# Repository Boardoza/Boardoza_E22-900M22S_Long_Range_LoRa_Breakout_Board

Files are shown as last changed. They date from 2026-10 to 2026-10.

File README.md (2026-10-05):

# Boardoza E22-900M22S LoRa® Breakout Board

The **Boardoza E22-900M22S Breakout Board** is a compact long-range wireless communication board based on the **Ebyte E22-900M22S** LoRa® module. Powered by the **Semtech SX1262** RF transceiver, it supports both **LoRa®** and **FSK(Frequency Shift Keying)** modulation, enabling reliable low-power wireless communication over the **850–930 MHz ISM frequency range**, including the widely used **868 MHz** and **915 MHz** bands. The onboard **32 MHz TCXO (Temperature Compensated Crystal Oscillator)** provides excellent frequency stability, making it suitable for narrowband communication and outdoor deployments.

The breakout board exposes the module's **SPI interface**, RF control signals, and status pins through standard headers, allowing easy integration with development platforms such as **STM32**, **ESP32**, **Arduino, and other 3.3V-compatible microcontrollers**. With its SMA antenna connector, industrial operating temperature range, and long communication distance, this board is ideal for **IoT gateways, smart agriculture, telemetry, environmental monitoring, industrial automation, and wireless sensor networks**.

---

## Key Features

- **Long-Range LoRa® Communication:** Based on the Semtech SX1262 transceiver for reliable long-distance wireless links.
- **868 / 915 MHz ISM Band Support:** Compatible with license-free ISM bands used worldwide.
- **High RF Output Power:** Up to **22 dBm (160 mW)** transmit power with software-adjustable output levels.
- **LoRa® and FSK Modulation Support:** Provides air data rates from 0.018 to 62.5 kbps in LoRa® mode and up to 300 kbps in FSK mode.
- **Stable RF Performance:** Integrated **32 MHz TCXO** improves frequency stability over temperature.
- **Easy MCU Integration:** Standard **4-wire SPI interface** with dedicated control and status signals.
- **SMA Antenna Connector:** Ready for external antennas with improved RF performance.
- **Ideal for IoT Applications:** Suitable for wireless sensor networks, smart agriculture, telemetry, industrial monitoring, and remote data acquisition.

---

## Technical Specifications

**Model:** E22-900M22S   
**Manufacturer:** Boardoza    
**Manufacturer IC:** Chengdu Ebyte Electronic Technology Co., Ltd.   
**RF Transceiver:** Semtech SX1262  
**Input Voltage:** 3.3V – 5.5V     
**Interface:** SPI  
**Frequency Range:** 850 – 930 MHz     
**Maximum RF Output Power:** 22 dBm (160 mW)  
**Maximum Air Data Rate (LoRa®):** 0.018 to 62.5 kbps  
**Maximum Air Data Rate (FSK):** 300 kbps  
**FIFO Buffer:** 256 Bytes  
**Oscillator:** High-Precision 32 MHz TCXO  
**Antenna Connector:** SMA Female  
**Operating Temperature:** -40°C to +85°C  
**Board Dimensions:** 40 mm × 20 mm

---

## Board Pinout

### ( J1 ) SPI Interface

| Pin Number | Pin Name | Description |
|:---:|:---:|---|
| 1 | VCC | Power Input |
| 2 | MISO | SPI Data Output |
| 3 | MOSI | SPI Data Input |
| 4 | SCK | SPI Clock |
| 5 | nCS | SPI Chip Select (Active Low) |
| 6 | GND | Ground |

### ( J2 ) Control Signals

| Pin Number | Pin Name | Description |
|:---:|:---:|---|
| 1 | NRST | Reset Input (Active Low) |
| 2 | BUSY | Module Busy Status Output |
| 3 | DIO1 | Configurable Digital I/O |

### ( J3 ) RF Switch & Control

| Pin Number | Pin Name | Description |
|:---:|:---:|---|
| 1 | RXEN | RF Receive Enable (Active High) |
| 2 | TXEN | RF Transmit Enable (Active High) |
| 3 | DIO2 | Configurable Digital I/O / RF Switch Control |

### ( J4 ) RF Connector

| Connector | Description |
|:---:|---|
| SMA Female | External 50Ω Antenna Connection |

---

## Board Dimensions

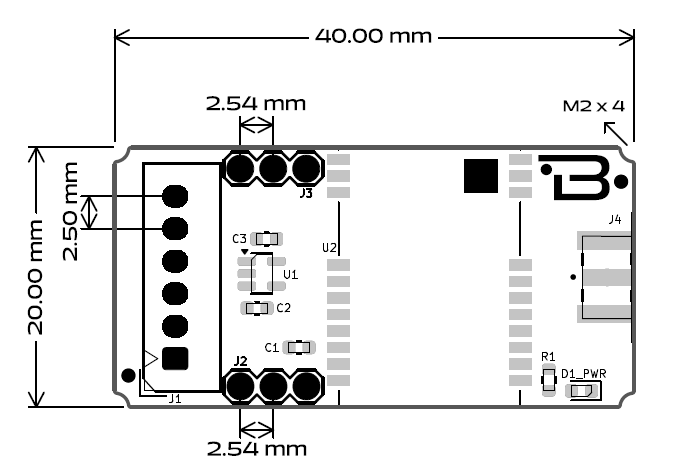
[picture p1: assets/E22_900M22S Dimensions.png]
Board Dimensions


---

## Step Files

[Boardoza E22-900M22S.step](./assets/E22_900M22S%20Step.step)

---

## Datasheet

[E22-900M22S Datasheet.pdf](./assets/E22-900M22S%20Datasheet.pdf)

---

## Version History

- V1.0.0 - Initial Release

---

## Support

- If you have any questions or need support, please contact **support@boardoza.com**

---

## **License**

This repository contains both hardware and software components:

### **Hardware Design**

[][cc-by-sa]

All hardware design files are licensed under [Creative Commons Attribution-ShareAlike 4.0 International License][cc-by-sa].

[cc-by-sa]: http://creativecommons.org/licenses/by-sa/4.0/
[cc-by-sa-shield]: https://img.shields.io/badge/License-CC%20BY--SA%204.0-lightgrey.svg

### **Software/Firmware**

[][bsd]

All software and firmware are licensed under [BSD 3-Clause License][bsd].

[bsd]: https://opensource.org/licenses/BSD-3-Clause
[bsd-shield]: https://img.shields.io/badge/License-BSD%203--Clause-blue.svg

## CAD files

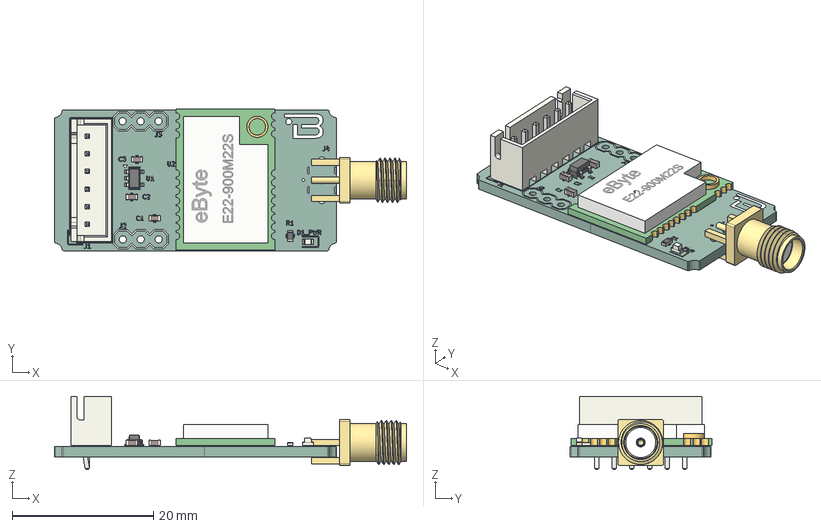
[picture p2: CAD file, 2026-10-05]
assets/E22_900M22S Step.step
49.9 x 20.1 x 10.4 mm
E22-900M22S v2
R_0603_1608Metric
C_0603_1608Metric x 3
Dielectric
Pin
SOT-23-5
JST_XH_B6B-XH-A_1x06_P2.50mm_Vertical
LED_0603_1608Metric
B-E22_900M22S-Brk-R1.0_silkscreen
B-E22_900M22S-Brk-R1.0_PCB

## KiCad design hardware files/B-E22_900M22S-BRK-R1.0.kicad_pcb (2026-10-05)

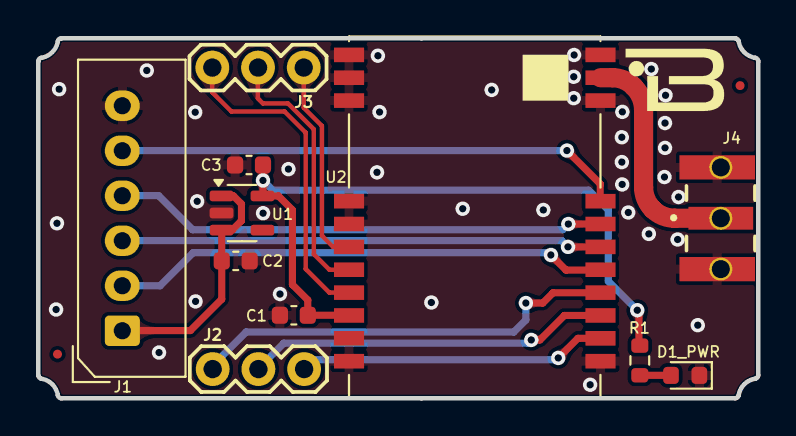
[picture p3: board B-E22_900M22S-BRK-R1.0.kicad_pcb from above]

Board: 2 copper layers, 40.0 x 20.0 mm, 11 parts (0 on the bottom side), 15 nets.

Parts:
C1: 100nF; C_0603_1608Metric
C2, C3: 1uF; C_0603_1608Metric
D1_PWR: LED POWER; LED_0603_1608Metric
J1: 2317-06S; 2317-06S_1x06_P2.50mm_Vertical
J2, J3: CONN_03; 1X03
J4: SMA; SMA-J-P-H-ST-EM1
R1: 330R; R_0603_1608Metric
U1: TLV73333PDBVR; SOT-23-5
U2: E22-400M22S; E22-900M22S

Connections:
+3V3: C1.1, C3.1, R1.1, U1.5 (OUT), U2.P$9 (VCC)
ANT: J4.1, U2.ANT
BUSY: J2.2, U2.P$14 (BUSY)
CS: J1.5, U2.P$19 (NSS)
DIO1: J2.3, U2.P$13 (DIO1)
DIO2: J3.3, U2.P$8 (DIO2)
GND: C1.2, C2.2, C3.2, D1_PWR.1 (K), J1.6, J4.2, J4.3, U1.2 (GND), U2.P$1 (GND1), U2.P$2 (GND1), U2.P$3 (GND1), U2.P$4 (GND1), U2.P$5 (GND1), U2.P$10 (GND1), U2.P$11 (GND1), U2.P$12 (GND1), U2.P$20 (GND1), U2.P$22 (GND1)
MISO: J1.2, U2.P$16 (MISO)
MOSI: J1.3, U2.P$17 (MOSI)
NRST: J2.1, U2.P$15 (NRST)
unnamed: D1_PWR.2 (A), R1.2
RXEN: J3.1, U2.P$6 (RXEN)
SCK: J1.4, U2.P$18 (SCK)
TXEN: J3.2, U2.P$7 (TXEN)
VCC: C2.1, J1.1, U1.1 (IN), U1.3 (EN)

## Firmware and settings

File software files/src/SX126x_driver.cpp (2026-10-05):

#include <SX126x_driver.h>

SPIClass* sx126x_spi = &SX126X_SPI;
uint32_t sx126x_spiFrequency = SX126X_SPI_FREQUENCY;
int8_t sx126x_nss = SX126X_PIN_NSS;
int8_t sx126x_busy = SX126X_PIN_BUSY;

/**
 * @brief Set the SPI object and frequency for SX126x communication.
 * @param SpiObject Reference to SPIClass object.
 * @param frequency SPI frequency in Hz.
 */
void sx126x_setSPI(SPIClass &SpiObject, uint32_t frequency)
{
    sx126x_spi = &SpiObject;
    sx126x_spiFrequency = frequency ? frequency : sx126x_spiFrequency;
}

/**
 * @brief Set the NSS (chip select) and BUSY pin numbers.
 * @param nss NSS pin number.
 * @param busy BUSY pin number.
 */
void sx126x_setPins(int8_t nss, int8_t busy)
{
    sx126x_nss = nss;
    sx126x_busy = busy;
}

/**
 * @brief Reset the SX126x device using the reset pin.
 * @param reset Reset pin number.
 */
void sx126x_reset(int8_t reset)
{
    pinMode(reset, OUTPUT);
    digitalWrite(reset, LOW);
    delayMicroseconds(500);
    digitalWrite(reset, HIGH);
    delayMicroseconds(100);
}

/**
 * @brief Initialize the SX126x device (set pin modes and begin SPI).
 */
void sx126x_begin()
{
    pinMode(sx126x_nss, OUTPUT);
    pinMode(sx126x_busy, INPUT);
    sx126x_spi->begin();
}

/**
 * @brief Check if the SX126x device is busy, with timeout.
 * @param timeout Timeout in milliseconds.
 * @return true if busy, false otherwise.
 */
bool sx126x_busyCheck(uint32_t timeout)
{
    uint32_t t = millis();
    while (digitalRead(sx126x_busy) == HIGH) if (millis() - t > timeout) return true;
    return false;
}

/**
 * @brief Put the SX126x device into sleep mode.
 * @param sleepConfig Sleep configuration value.
 */
void sx126x_setSleep(uint8_t sleepConfig)
{
    sx126x_transfer(0x84, &sleepConfig, 1);
}

/**
 * @brief Set the SX126x device to standby mode.
 * @param standbyConfig Standby configuration value.
 */
void sx126x_setStandby(uint8_t standbyConfig)
{
    sx126x_transfer(0x80, &standbyConfig, 1);
}

/**
 * @brief Set the SX126x device to frequency synthesis mode.
 */
void sx126x_setFs()
{
    sx126x_transfer(0xC1, NULL, 0);
}

/**
 * @brief Set the SX126x device to transmit mode with timeout.
 * @param timeout Timeout value.
 */
void sx126x_setTx(uint32_t timeout)
{
    uint8_t buf[3];
    buf[0] = timeout >> 16;
    buf[1] = timeout >> 8;
    buf[2] = timeout;
    sx126x_transfer(0x83, buf, 3);
}

/**
 * @brief Set the SX126x device to receive mode with timeout.
 * @param timeout Timeout value.
 */
void sx126x_setRx(uint32_t timeout)
{
    uint8_t buf[3];
    buf[0] = timeout >> 16;
    buf[1] = timeout >> 8;
    buf[2] = timeout;
    sx126x_transfer(0x82, buf, 3);
}

/**
 * @brief Stop timer on preamble detection.
 * @param enable Enable or disable (1 or 0).
 */
void sx126x_stopTimerOnPreamble(uint8_t enable)
{
    sx126x_transfer(0x9F, &enable, 1);
}

/**
 * @brief Set RX duty cycle (periodic RX and sleep).
 * @param rxPeriod RX period.
 * @param sleepPeriod Sleep period.
 */
void sx126x_setRxDutyCycle(uint32_t rxPeriod, uint32_t sleepPeriod)
{
    uint8_t buf[6];
    buf[0] = rxPeriod >> 16;
    buf[1] = rxPeriod >> 8;
    buf[2] = rxPeriod;
    buf[3] = sleepPeriod >> 16;
    buf[4] = sleepPeriod >> 8;
    buf[5] = sleepPeriod;
    sx126x_transfer(0x94, buf, 6);
}

/**
 * @brief Set the SX126x device to CAD (Channel Activity Detection) mode.
 */
void sx126x_setCad()
{
    sx126x_transfer(0xC5, NULL, 0);
}

/**
 * @brief Set the SX126x device to transmit continuous wave mode.
 */
void sx126x_setTxContinuousWave()
{
    sx126x_transfer(0xD1, NULL, 0);
}

/**
 * @brief Set the SX126x device to transmit infinite preamble mode.
 */
void sx126x_setTxInfinitePreamble()
{
    sx126x_transfer(0xD2, NULL, 0);
}

/**
 * @brief Set the regulator mode.
 * @param modeParam Regulator mode parameter.
 */
void sx126x_setRegulatorMode(uint8_t modeParam)
{
    sx126x_transfer(0x96, &modeParam, 1);
}

/**
 * @brief Calibrate the SX126x device.
 * @param calibParam Calibration parameter.
 */
void sx126x_calibrate(uint8_t calibParam)
{
    sx126x_transfer(0x89, &calibParam, 1);
}

/**
 * @brief Calibrate the image rejection for a given frequency range.
 * @param freq1 First frequency calibration value.
 * @param freq2 Second frequency calibration value.
 */
void sx126x_calibrateImage(uint8_t freq1, uint8_t freq2)
{
    uint8_t buf[2];
    buf[0] = freq1;
    buf[1] = freq2;
    sx126x_transfer(0x98, buf, 2);
}

/**
 * @brief Set the power amplifier configuration.
 * @param paDutyCycle PA duty cycle.
 * @param hpMax High power max.
 * @param deviceSel Device selection.
 * @param paLut PA LUT value.
 */
void sx126x_setPaConfig(uint8_t paDutyCycle, uint8_t hpMax, uint8_t deviceSel, uint8_t paLut)
{
    uint8_t buf[4];
    buf[0] = paDutyCycle;
    buf[1] = hpMax;
    buf[2] = deviceSel;
    buf[3] = paLut;
    sx126x_transfer(0x95, buf, 4);
}

/**
 * @brief Set the RX/TX fallback mode.
 * @param fallbackMode Fallback mode value.
 */
void sx126x_setRxTxFallbackMode(uint8_t fallbackMode)
{
    sx126x_transfer(0x93, &fallbackMode, 1);
}

/**
 * @brief Write data to a register address.
 * @param address Register address.
 * @param data Pointer to data array.
 * @param nData Number of bytes to write.
 */
void sx126x_writeRegister(uint16_t address, uint8_t* data, uint8_t nData)
{
    uint8_t bufAdr[2] = {address >> 8, address};
    sx126x_transfer(0x0D, data, nData, bufAdr, 2, false);
}

/**
 * @brief Read data from a register address.
 * @param address Register address.
 * @param data Pointer to data array.
 * @param nData Number of bytes to read.
 */
void sx126x_readRegister(uint16_t address, uint8_t* data, uint8_t nData)
{
    uint8_t bufAdr[3] = {address >> 8, address, 0x00};
    sx126x_transfer(0x1D, data, nData, bufAdr, 3, true);
}

/**
 * @brief Write data to the transmit buffer.
 * @param offset Buffer offset.
 * @param data Pointer to data array.
 * @param nData Number of bytes to write.
 */
void sx126x_writeBuffer(uint8_t offset, uint8_t* data, uint8_t nData)
{
    uint8_t bufOfs[1] = {offset};
    sx126x_transfer(0x0E, data, nData, bufOfs, 1, false);
}

/**
 * @brief Read data from the receive buffer.
 * @param offset Buffer offset.
 * @param data Pointer to data array.
 * @param nData Number of bytes to read.
 */
void sx126x_readBuffer(uint8_t offset, uint8_t* data, uint8_t nData)
{
    uint8_t bufOfs[2] = {offset, 0x00};
    sx126x_transfer(0x1E, data, nData, bufOfs, 2, true);
}

/**
 * @brief Set DIO IRQ parameters for the device.
 * @param irqMask IRQ mask.
 * @param dio1Mask DIO1 mask.
 * @param dio2Mask DIO2 mask.
 * @param dio3Mask DIO3 mask.
 */
void sx126x_setDioIrqParams(uint16_t irqMask, uint16_t dio1Mask, uint16_t dio2Mask, uint16_t dio3Mask)
{
    uint8_t buf[8];
    buf[0] = irqMask >> 8;
    buf[1] = irqMask;
    buf[2] = dio1Mask >> 8;
    buf[3] = dio1Mask;
    buf[4] = dio2Mask >> 8;
    buf[5] = dio2Mask;
    buf[6] = dio3Mask >> 8;
    buf[7] = dio3Mask;
    sx126x_transfer(0x08, buf, 8);
}
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

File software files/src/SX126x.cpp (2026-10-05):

#include <SX126x.h>

/**
 * @brief Function pointer for transmit callback.
 */
void (*SX126x::_onTransmit)();

/**
 * @brief Function pointer for receive callback.
 */
void (*SX126x::_onReceive)();

/**
 * @brief Stores IRQ status.
 */
volatile uint16_t SX126x::_statusIrq = 0xFFFF;

/**
 * @brief Stores transmit time in milliseconds.
 */
uint32_t SX126x::_transmitTime = 0;

/**
 * @brief Buffer index for TX/RX operations.
 */
uint8_t SX126x::_bufferIndex = 0;

/**
 * @brief Payload length for TX/RX operations.
 */
uint8_t SX126x::_payloadTxRx = 0;

/**
 * @brief Static IRQ pin number.
 */
int8_t SX126x::_irqStatic = -1;

/**
 * @brief Pin to set LOW after TX/RX.
 */
int8_t SX126x::_pinToLow = -1;

/**
 * @brief SX126x constructor. Initializes SPI and default pins.
 */
SX126x::SX126x()
{
    _spi = &SX126X_SPI;
    _dio = SX126X_PIN_RF_IRQ;
    setPins(SX126X_PIN_NSS, SX126X_PIN_RESET, SX126X_PIN_BUSY);
}

/**
 * @brief Initializes the SX126x module and sets it to LoRa mode.
 * @return true if initialization is successful, false otherwise.
 */
bool SX126x::begin()
{
    // set pins as input or output
    if (_irq != -1) pinMode(_irq, INPUT);
    if (_txen != -1) pinMode(_txen, OUTPUT);
    if (_rxen != -1) pinMode(_rxen, OUTPUT);

    // begin spi and perform device reset
    sx126x_begin();
    sx126x_reset(_reset);

    // check if device connect and set modem to LoRa
    sx126x_setStandby(SX126X_STANDBY_RC);
    if (getMode() != SX126X_STATUS_MODE_STDBY_RC) return false;
    sx126x_setPacketType(SX126X_LORA_MODEM);
    
    sx126x_fixResistanceAntenna();
    return true;
}

/**
 * @brief Initializes the SX126x module with custom pin configuration.
 * @param nss NSS (chip select) pin.
 * @param reset Reset pin.
 * @param busy Busy pin.
 * @param irq IRQ pin.
 * @param txen TX enable pin.
 * @param rxen RX enable pin.
 * @return true if initialization is successful, false otherwise.
 */
bool SX126x::begin(int8_t nss, int8_t reset, int8_t busy, int8_t irq, int8_t txen, int8_t rxen)
{
    setPins(nss, reset, busy, irq, txen, rxen);
    return begin();
}

/**
 * @brief Ends communication and puts the device to sleep.
 */
void SX126x::end()
{
    sleep(SX126X_SLEEP_COLD_START);
    _spi->end();
}

/**
 * @brief Resets the SX126x device.
 * @return true if reset is successful, false otherwise.
 */
bool SX126x::reset()
{
    // put reset pin to low then wait busy pin to low
    sx126x_reset(_reset);
    return !sx126x_busyCheck();
}

/**
 * @brief Puts the device into sleep mode.
 * @param option Sleep mode option.
 */
void SX126x::sleep(uint8_t option)
{
    // put device in sleep mode, wait for 500 us to enter sleep mode
    standby();
    sx126x_setSleep(option);
    delayMicroseconds(500);
}

/**
 * @brief Wakes the device from sleep mode.
 */
void SX126x::wake()
{
    // wake device by set nss to low and put device in standby mode
    digitalWrite(_nss, LOW);
    standby();
    sx126x_fixResistanceAntenna();
}

/**
 * @brief Sets the device to standby mode.
 * @param option Standby mode option.
 */
void SX126x::standby(uint8_t option)
{
    sx126x_setStandby(option);
}

/**
 * @brief Sets the SPI and pin configuration to active for this object.
 */
void SX126x::setActive()
{
    // override spi, nss, and busy static property in SX126x driver with object property
    sx126x_setSPI(*_spi, 0);
    sx126x_setPins(_nss, _busy);
}

/**
 * @brief Checks if the device is busy.
 * @param timeout Timeout in milliseconds.
 * @return true if busy, false otherwise.
 */
bool SX126x::busyCheck(uint32_t timeout)
{
    return sx126x_busyCheck(timeout);
}

/**
 * @brief Sets the fallback mode for RX/TX.
 * @param fallbackMode Fallback mode value.
 */
void SX126x::setFallbackMode(uint8_t fallbackMode)
{
    sx126x_setRxTxFallbackMode(fallbackMode);
}

/**
 * @brief Gets the current mode of the device.
 * @return Mode value.
 */
uint8_t SX126x::getMode()
{
    uint8_t mode;
    sx126x_getStatus(&mode);
    return mode & 0x70;
}

/**
 * @brief Sets the SPI object and frequency.
 * @param SpiObject Reference to SPIClass object.
 * @param frequency SPI frequency in Hz.
 */
void SX126x::setSPI(SPIClass &SpiObject, uint32_t frequency)
{
    sx126x_setSPI(SpiObject, frequency);

    _spi = &SpiObject;
}

/**
 * @brief Sets the pin configuration for the device.
 * @param nss NSS (chip select) pin.
 * @param reset Reset pin.
 * @param busy Busy pin.
 * @param irq IRQ pin.
 * @param txen TX enable pin.
 * @param rxen RX enable pin.
 */
void SX126x::setPins(int8_t nss, int8_t reset, int8_t busy, int8_t irq, int8_t txen, int8_t rxen)
{
    sx126x_setPins(nss, busy);

    _nss = nss;
    _reset = reset;
    _busy = busy;
    _irq = irq;
    _txen = txen;
    _rxen = rxen;
    _irqStatic = digitalPinToInterrupt(_irq);
}

/**
 * @brief Sets the RF IRQ pin (DIO1, DIO2, or DIO3).
 * @param dioPinSelect DIO pin selection (1, 2, or 3).
 */
void SX126x::setRfIrqPin(int8_t dioPinSelect)
{
    if ((dioPinSelect == 2) || (dioPinSelect == 3)) _dio = dioPinSelect;
    else _dio = 1;
}

/**
 * @brief Enables or disables DIO2 as RF switch control.
 * @param enable True to enable, false to disable.
 */
void SX126x::setDio2RfSwitch(bool enable)
{
    if (enable) sx126x_setDio2AsRfSwitchCtrl(SX126X_DIO2_AS_RF_SWITCH);
    else sx126x_setDio2AsRfSwitchCtrl(SX126X_DIO2_AS_IRQ);
}

/**
 * @brief Sets DIO3 as TCXO control with voltage and delay.
 * @param tcxoVoltage TCXO voltage.
 * @param delayTime Delay time in microseconds.
 */
void SX126x::setDio3TcxoCtrl(uint8_t tcxoVoltage, uint32_t delayTime)
{
    sx126x_setDio3AsTcxoCtrl(tcxoVoltage, delayTime);
    sx126x_setStandby(SX126X_STANDBY_RC);
    sx126x_calibrate(0xFF);
}

/**
 * @brief Sets the crystal capacitor values.
 * @param xtalA Value for XTAL A.
 * @param xtalB Value for XTAL B.
 */
void SX126x::setXtalCap(uint8_t xtalA, uint8_t xtalB)
{
    sx126x_setStandby(SX126X_STANDBY_XOSC);
    uint8_t buf[2] = {xtalA, xtalB};
    sx126x_writeRegister(SX126X_REG_XTA_TRIM, buf, 2);
    sx126x_setStandby(SX126X_STANDBY_RC);
    sx126x_calibrate(0xFF);
}

/**
 * @brief Sets the regulator mode.
 * @param regMode Regulator mode value.
 */
void SX126x::setRegulator(uint8_t regMode)
{
    sx126x_setRegulatorMode(regMode);
}

/**
 * @brief Sets the current protection value.
 * @param current Current value in mA.
 */
void SX126x::setCurrentProtection(uint8_t current)
{
    uint8_t currentmA = current * 2 / 5;
    sx126x_writeRegister(SX126X_REG_OCP_CONFIGURATION, &currentmA, 1);
}

/**
 * @brief Gets the current modem type.
 * @return Modem type value.
 */
uint8_t SX126x::getModem()
{
    uint8_t modem;
    sx126x_getPacketType(&modem);
    return modem;
}

/**
 * @brief Sets the modem type.
 * @param modem Modem type value.
 */
void SX126x::setModem(uint8_t modem)
{
    _modem = modem;
    sx126x_setStandby(SX126X_STANDBY_RC);
    sx126x_setPacketType(modem);
}
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

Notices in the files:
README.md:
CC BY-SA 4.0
